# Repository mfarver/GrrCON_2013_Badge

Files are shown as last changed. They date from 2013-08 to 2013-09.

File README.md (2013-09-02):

GrrCON_2013_Badge
=================

Schematics, Board Designs and code for GrrCON 2013 Badges.

Schematic and Board layouts require Eagle 6.4.

Badge is based on Arduino Uno Rev 3.  http://arduino.cc

The board layout and schematic are released under the Creative Commons Share Alike license.  The GrrCON "skull" outline of the board should not be used without permission.

When programming the bootloader on the Main ATMEGA328P processor fuses are:
efuse:0x06 hfuse:0xD6 lfuse:0x7F

Custom bootloader and board definition in the hardware directory.

https://github.com/arduino/Arduino/blob/master/hardware/arduino/firmwares/atmegaxxu2/Arduino-COMBINED-dfu-usbserial-atmega16u2-Uno-Rev3.hex
lfuse:w:0xFF:m hfuse:w:0xD9:m efuse:w:0xF4:m lock:w:0x0F:m

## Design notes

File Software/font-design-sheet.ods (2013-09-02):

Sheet: Sheet1
 |  | 1 |  | 1 |  | 1 |  |  |  |  |  |  |  | 1 |  |  |  |  |  |  |  |  | 1 | 1 |  |  |  |  | 1 |  |  |  | 1 |  | 1
 |  | 1 |  | 1 |  | 1 |  | 1 |  | 1 |  |  | 1 | 1 | 1 | 1 | 1 |  |  |  | 1 | 1 |  |  | 1 |  |  |  | 1 |  |  | 1 |  |  |  | 1
 |  | 1 | 1 |  | 1 |  | 1 | 1 | 1 | 1 | 1 | 1 |  |  |  |  |  |  |  | 1 |  | 1 |  | 1 |  |  |  | 1 |  |  | 1 |  |  |  |  |  | 1
 |  | 1 |  |  |  |  |  | 1 |  | 1 |  |  | 1 | 1 | 1 |  |  |  | 1 |  |  |  | 1 |  |  |  |  |  |  |  | 1 |  |  |  |  |  | 1
 |  | 1 |  |  |  |  | 1 | 1 | 1 | 1 | 1 |  |  |  |  | 1 |  | 1 |  |  |  | 1 |  | 1 |  | 1 |  |  |  |  | 1 |  |  |  |  |  | 1
 |  |  |  |  |  |  |  | 1 |  | 1 |  | 1 | 1 | 1 | 1 |  | 1 |  |  |  | 1 | 1 |  |  | 1 |  |  |  |  |  |  | 1 |  |  |  | 1
 |  | 1 |  |  |  |  |  |  |  |  |  |  |  | 1 |  |  |  |  |  |  |  |  | 1 | 1 |  | 1 |  |  |  |  |  |  | 1 |  | 1
SPC | ! |  | “ |  |  |  | # |  |  |  |  | $ |  |  |  |  | % |  |  |  |  | & |  |  |  |  | ' |  |  | ( |  |  |  | )
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

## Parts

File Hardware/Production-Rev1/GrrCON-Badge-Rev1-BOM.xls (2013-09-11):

PARTS LIST FOR GRRCON 2013 BADGE
Qty | Value | Device | Part Number | Digikey Part | Parts
1 | 200ma | PTC-FUSE-US1206 | 0ZCA0020FF2E | 507-1478-1-ND | F2
1 | 1Mohm | 0805 Resistor 5% | ERJ-6GEYJ105V | P1.0MACT-ND | R1
2 | 270ohm | RESISTOR-DIL_4R-NCAY16 | CAY16-271J4LF | CAY16-271J4LFCT-ND | RN1, RN2
1 | 1kohm | RESISTOR-DIL_4R-NCAY16 | CAY16-102J4GLF | CAY16-102J4GLFCT-ND | RN3
3 | 1uf | 0805 Ceramic Cap | CC0805ZRY5V7BB105 | 311-1457-1-ND | C3, C4, C8
2 | 10k | 0805 Resistor 5% | ERJ-6GEYJ103V | P10KACT-ND | R3, R4
1 | 16mhz | CRYSTALSM49 | ABLS-16.000MHZ-B4-T | 535-10226-1-ND | Q1
2 | 22 ohm | 0805 Resistor 5% | ERJ-6GEYJ220V | P22ACT-ND | R6, R7
2 | 22pf | 0805 Ceramic Cap | CC0805JRNPO9BN220 | 311-1103-1-ND | C9, C11
2 | 74LS595D | 74LS595D shift register | 74HC595D,112 | 568-1483-1-ND | IC3, IC4
5 | 100n | 0805 Ceramic Cap | CC0805ZRY5V9BB104 | 311-1361-1-ND | C1, C2, C5, C6, C7
1 | ATMEGA16U2AU | ATMEGA16U2AU | ATMEGA16U2AU | ATMEGA16U2-AU-ND | IC1
1 | BLM21 | WE-CBF_0805 | BLM21PG221SN1D | 490-1054-1-ND | L1 |  | not populated on production
4 | CD1206-S01575 | DIODE-MINIMELF | CD1206-S01575 | CD1206-S01575CT-ND | D1, D2, D3, D4 |  | depending on LED color D1 may have to be replaced with a zero ohm jumper or Schottky diode
2 | CG0603MLC-05E | VARISTORCN0603 | CG0603MLC-05E | CG0603MLC-05ECT-ND | Z1, Z2 |  | not populated on production
1 | CSTCE16M0V53-R0 16MHZ | RESONATORMU | CSTCE16M0V53-R0 | 490-1198-6-ND | Y2
56 | Varied colors | LEDCHIP-LED0603 |  |  | LED1-LED56
1 | KEYSTONE_COIN2450 | KEYSTONE_COIN2450 | 3009 | 3009K-ND | B1
1 | MCP1703CB | MCP1703CB | MCP1703T-3302E/CB | MCP1703T-3302E/CBCT-ND | IC5
1 | PTS645SMT | PTS645SMT | PTS645SH50SMTR92 LFS | CKN9085CT-ND | SW1
1 | ATMEGA328P-AU | ATMEGA328P-AU | ATMEGA328P-AU | ATMEGA328P-AU-ND | IC2
 | Errata:
 | The pad layout of the pushbutton is wrong and will hold the system in reset. The trace between the lower two pads should be cut, and the upper right leg removed from the switch before soldering
 | The ATMEGA328P processor power net is not connected. A fix wire must be run from the lower (ungrounded) pad of C6 to a nearby VCC pad (we recommended pin 10 of IC4)
 | The forward voltage drop of diode D1 lowers the battery voltage enough that the white LEDs will not light. On most boards D1 is replaced with a 0 ohm jumper.
 | CAUTION: If D1 is replaced with a jumper the battery is not protected from the USB voltage. DO NOT LEAVE BATTERY INSERTED WHEN USB IS CONNECTED!
 | Schematics, code and layouts are available at https://github.com/mfarver/GrrCON_2013_Badge
 |  |  |  | Ebay link for LEDs | Cost each | Reel
 |  |  |  | http://www.ebay.com/itm/4000-pcs-one-reel-SMD-SMT-0603-Super-bright-White-LED-lamp-Bulb-HIGH-QUALITY-/300914219557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 | $62.00 | 2 | $124.00
 |  |  |  | http://www.ebay.com/itm/4000-pcs-one-reel-SMD-SMT-0603-Super-bright-Yellow-LED-lamp-Bulb-GOOD-QUALITY-/121120068712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 | $50.00 | 1 | $50.00
 |  |  |  | http://www.ebay.com/itm/4000-pcs-one-reel-SMD-SMT-0603-Super-bright-BLUE-LED-lamp-Bulb-GOOD-QUALITY-/290925081469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 | 50 | 1 | $50.00

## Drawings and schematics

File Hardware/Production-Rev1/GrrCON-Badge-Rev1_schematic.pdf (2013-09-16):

# GrrCON 2013 Badge

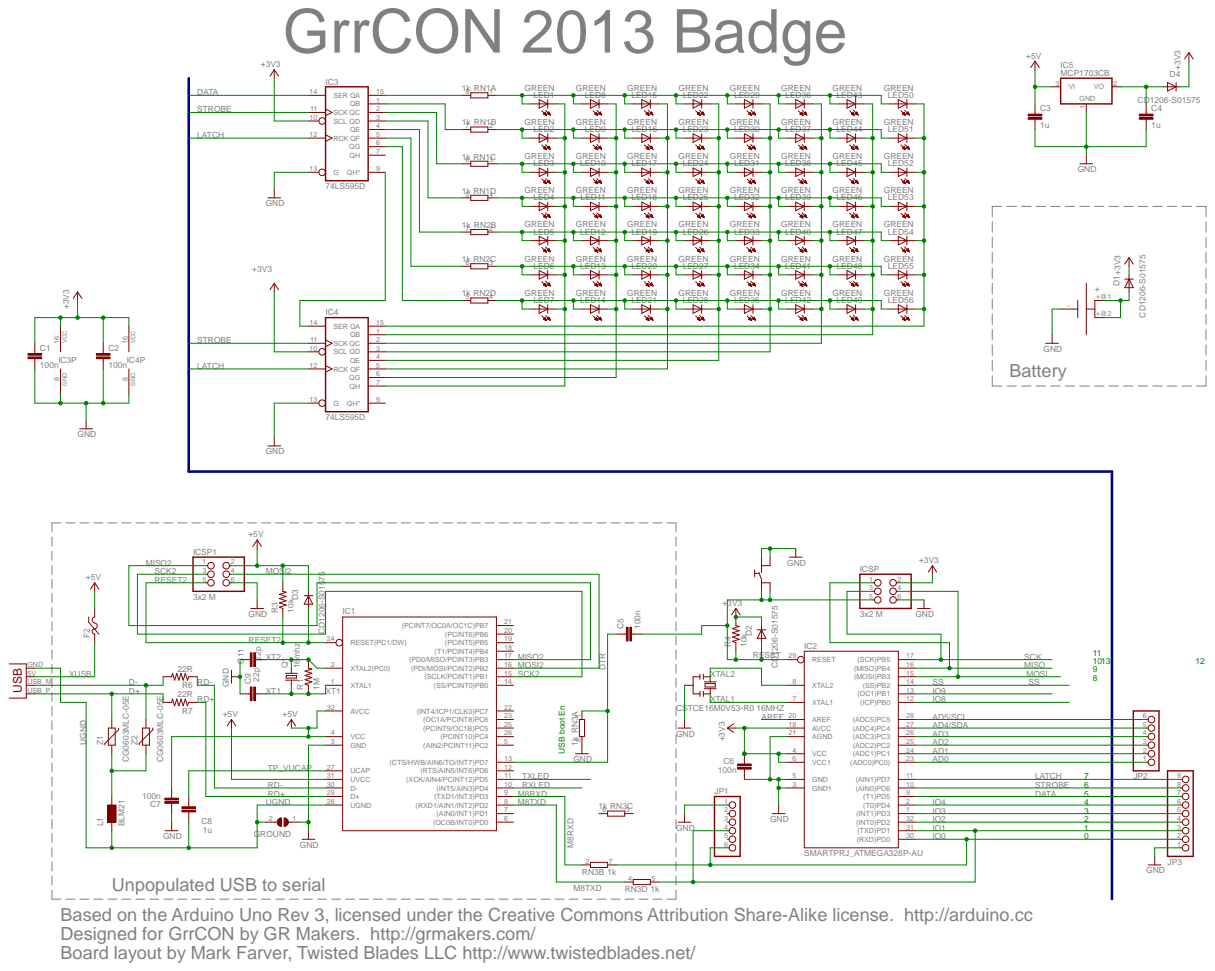
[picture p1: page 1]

Unpopulated USB to serial
Based on the Arduino Uno Rev 3, licensed under the Creative Commons Attribution Share-Alike license. http://arduino.cc
Designed for GrrCON by GR Makers. http://grmakers.com/
Board layout by Mark Farver, Twisted Blades LLC http://www.twistedblades.net/

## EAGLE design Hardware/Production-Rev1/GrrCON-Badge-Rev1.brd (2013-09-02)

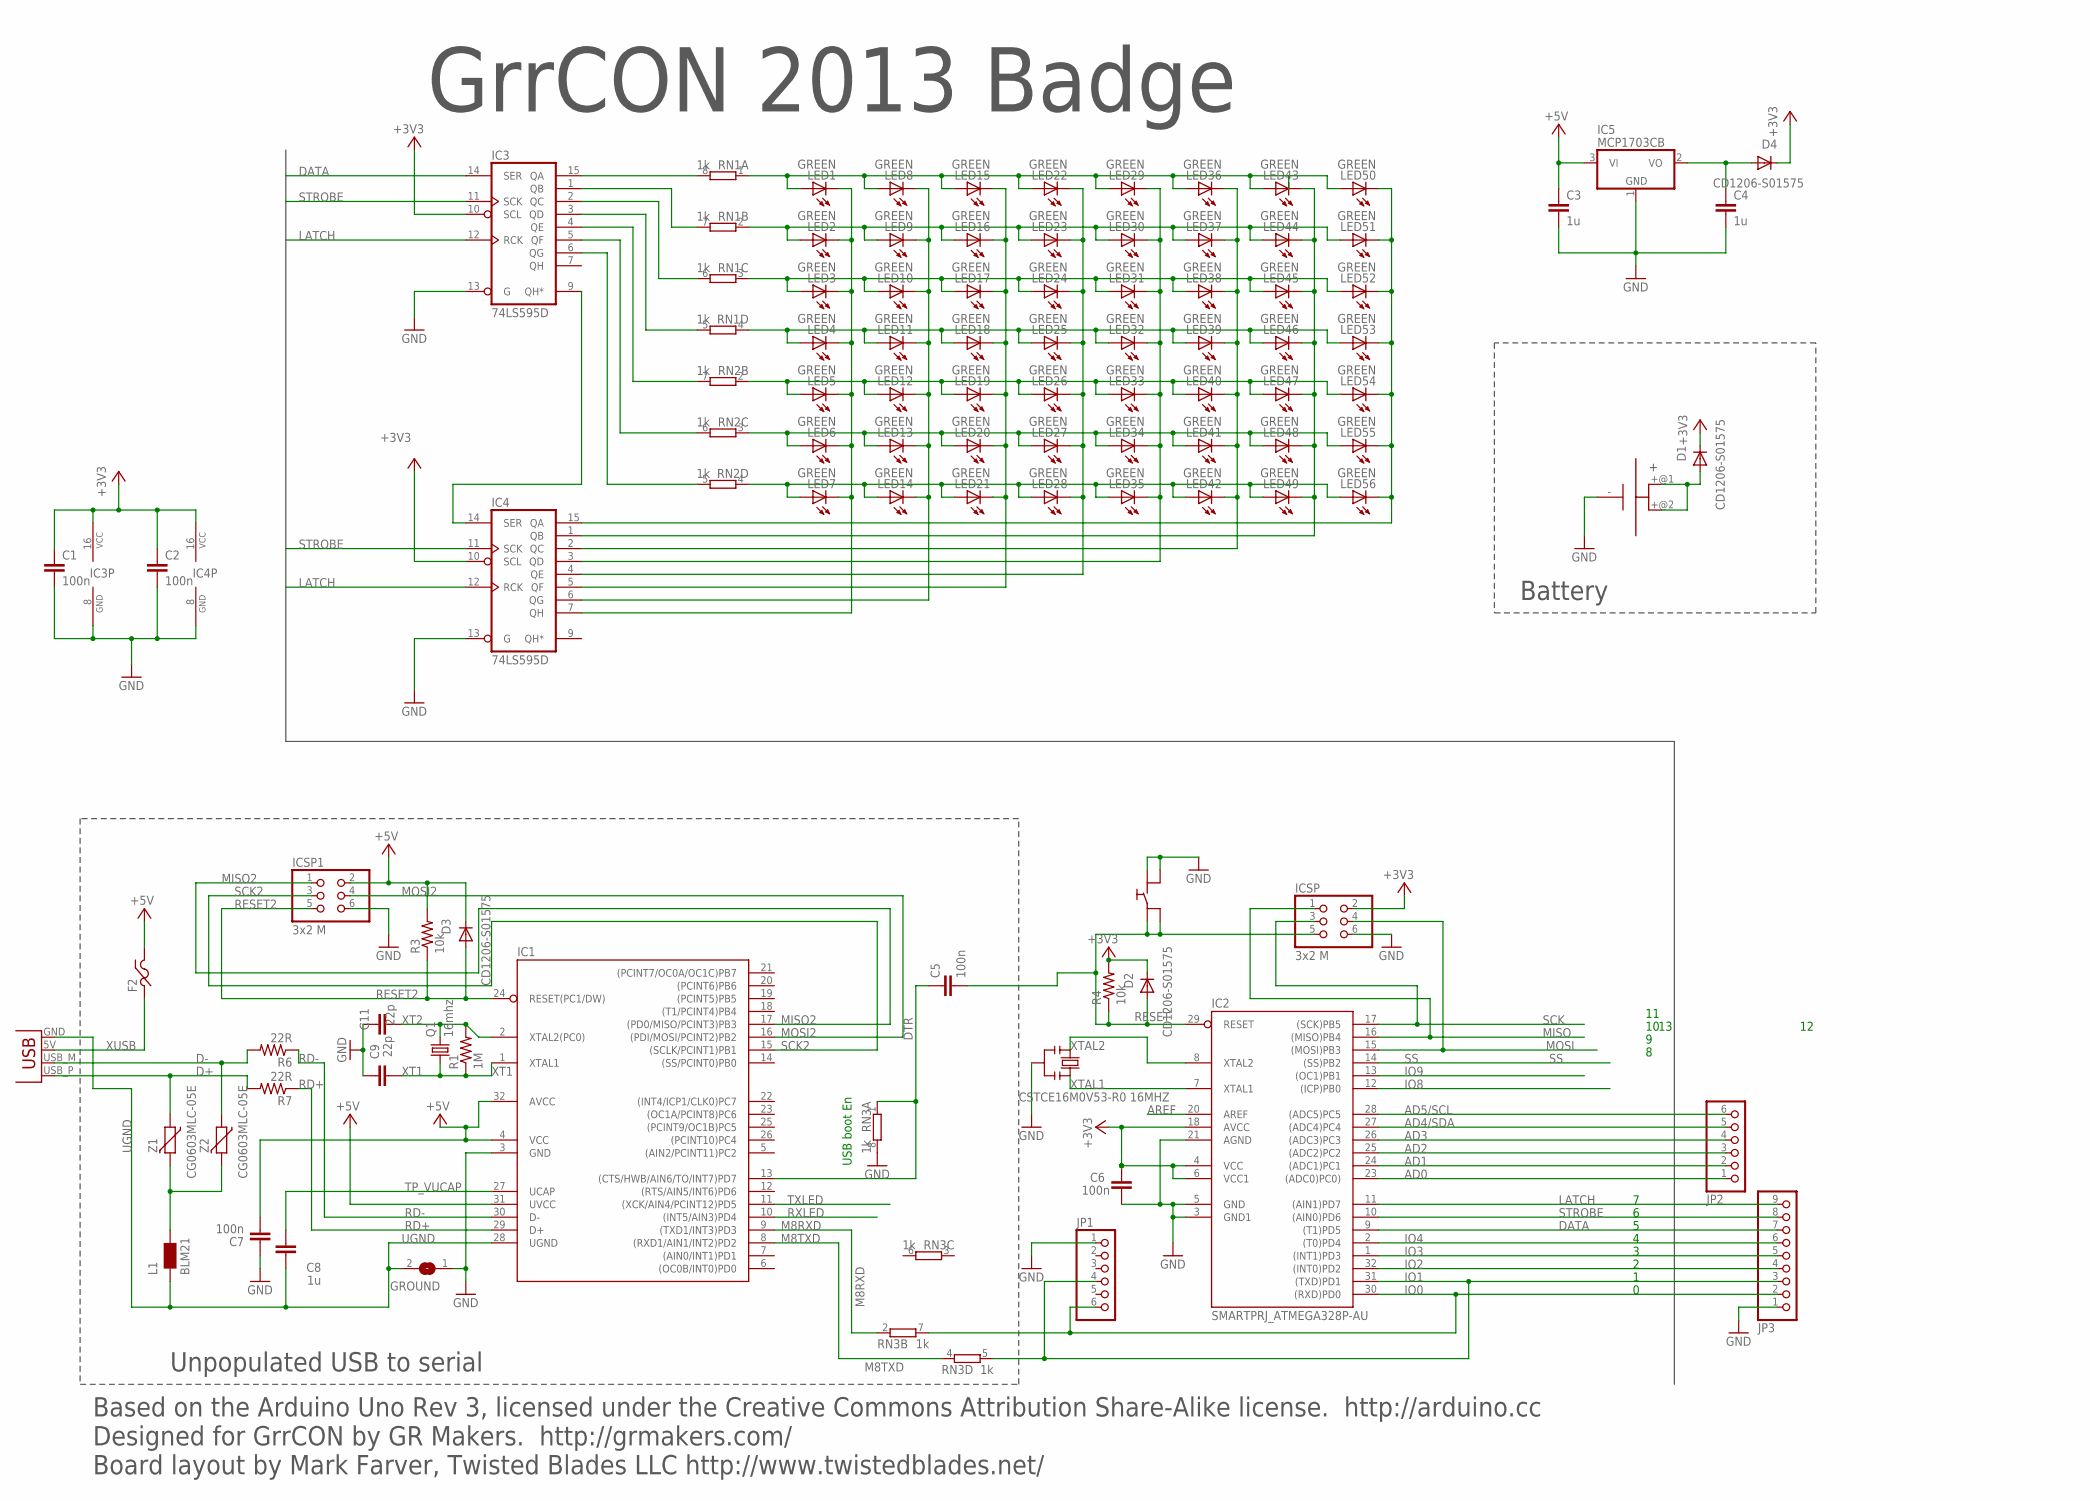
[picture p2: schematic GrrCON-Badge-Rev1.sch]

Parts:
B1: KEYSTONE_COIN2450; 3009
C1, C2, C5, C6, C7: 100n; C0805
C3, C4, C8: 1u; C0805
C9, C11: 22p; C0805
D1, D2, D3, D4: CD1206-S01575; MINIMELF
F2: PTC-FUSE-US1206; F1206
GROUND: SJ
IC1: ATMEGA16U2AU; SMARTPRJ_TQFP32-08
IC2: SMARTPRJ_ATMEGA328P-AU; SMARTPRJ_TQFP32-08
IC3, IC4: 74LS595D; SO16
IC5: MCP1703CB; SOT23
ICSP, ICSP1: 3x2 M; 2X03
JP1, JP2: PINHD-1X6; 1X06
JP3: PINHD-1X9; 1X09
L1: BLM21; 0805
LED1, LED2, LED3, LED4, LED5, LED6, LED7, LED8, LED9, LED10, LED11, LED12, LED13, LED14, LED15, LED16, LED17, LED18, LED19, LED20, LED21, LED22, LED23, LED24, LED25, LED26, LED27, LED28, LED29, LED30, LED31, LED32, LED33, LED34, LED35, LED36, LED37, LED38, LED39, LED40, LED41, LED42, LED43, LED44, LED45, LED46, LED47, LED48, LED49, LED50, LED51, LED52, LED53, LED54, LED55, LED56: GREEN; CHIPLED_0603
Q1: 16mhz; SM49
R1: 1M; R0805
R3, R4: 10k; R0805
R6, R7: 22R; R0805
RN1, RN2, RN3: 1k; RESISTOR-DIL_CAY16
SW1: PTS645SMT
X1: USBPCB; USB-A-PCB
Y2: CSTCE16M0V53-R0 16MHZ; RESONATOR
Z1, Z2: CG0603MLC-05E; CT/CN0603

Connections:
+3V3: C1.1, C2.1, C6.2, D1.C, D2.C, D4.C, IC2.4 (VCC), IC2.6 (VCC1), IC2.18 (AVCC), IC3.10 (SCL), IC3.16 (VCC), IC4.10 (SCL), IC4.16 (VCC), ICSP.2, R4.2
+5V: C3.1, C7.1, D3.C, F2.2, IC1.4 (VCC), IC1.31 (UVCC), IC1.32 (AVCC), IC5.3 (VI), ICSP1.2, R3.2
AD0: IC2.23 ((ADC0)PC0)), JP2.1
AD1: IC2.24 ((ADC1)PC1), JP2.2
AD2: IC2.25 ((ADC2)PC2), JP2.3
AD3: IC2.26 ((ADC3)PC3), JP2.4
AD4/SDA: IC2.27 ((ADC4)PC4), JP2.5
AD5/SCL: IC2.28 ((ADC5)PC5), JP2.6
AREF: IC2.20 (AREF)
D+: R7.2, X1.USB_P (D+), Z1.1
D-: R6.2, X1.USB_M (D-), Z2.1
DATA: IC2.9 ((T1)PD5), IC3.14 (SER), JP3.7
DTR: C5.1, IC1.13 ((CTS/HWB/AIN6/TO/INT7)PD7), RN3.1
GND: B1.-, C1.2, C2.2, C3.2, C4.2, C6.1, C7.2, C9.2, C11.2, GROUND.1, IC1.3 (GND), IC2.3 (GND1), IC2.5 (GND), IC2.21 (AGND), IC3.8 (GND), IC3.13 (G), IC4.8 (GND), IC4.13 (G), IC5.1 (GND), ICSP.6, ICSP1.6, JP1.1, JP3.1, RN3.8 (2), SW1.2A, SW1.2B, Y2.2
IO0: IC2.30 ((RXD)PD0), JP1.6, JP3.2, RN3.7 (2)
IO1: IC2.31 ((TXD)PD1), JP1.4, JP3.3, RN3.5 (2)
IO2: IC2.32 ((INT0)PD2), JP3.4
IO3: IC2.1 ((INT1)PD3), JP3.5
IO4: IC2.2 ((T0)PD4), JP3.6
IO8: IC2.12 ((ICP)PB0)
IO9: IC2.13 ((OC1)PB1)
LATCH: IC2.11 ((AIN1)PD7), IC3.12 (RCK), IC4.12 (RCK), JP3.9
M8RXD: IC1.9 ((TXD1/INT3)PD3), RN3.2 (1)
M8TXD: IC1.8 ((RXD1/AIN1/INT2)PD2), RN3.4 (1)
MISO: IC2.16 ((MISO)PB4), ICSP.1
MISO2: IC1.17 ((PD0/MISO/PCINT3)PB3), ICSP1.1
MOSI: IC2.15 ((MOSI)PB3), ICSP.4
MOSI2: IC1.16 ((PDI/MOSI/PCINT2)PB2), ICSP1.4
unnamed: IC4.7 (QH), LED1.C, LED2.C, LED3.C, LED4.C, LED5.C, LED6.C, LED7.C
unnamed: LED2.A, LED9.A, LED16.A, LED23.A, LED30.A, LED37.A, LED44.A, LED51.A, RN1.2 (1)
unnamed: IC3.6 (QG), RN2.5 (2)
unnamed: LED3.A, LED10.A, LED17.A, LED24.A, LED31.A, LED38.A, LED45.A, LED52.A, RN1.3 (1)
unnamed: LED4.A, LED11.A, LED18.A, LED25.A, LED32.A, LED39.A, LED46.A, LED53.A, RN1.4 (1)
unnamed: IC3.9 (QH*), IC4.14 (SER)
unnamed: IC3.5 (QF), RN2.6 (2)
unnamed: IC3.4 (QE), RN2.7 (2)
unnamed: IC3.3 (QD), RN1.5 (2)
unnamed: IC4.6 (QG), LED8.C, LED9.C, LED10.C, LED11.C, LED12.C, LED13.C, LED14.C
unnamed: IC3.2 (QC), RN1.6 (2)
unnamed: IC3.1 (QB), RN1.7 (2)
unnamed: IC3.15 (QA), RN1.8 (2)
unnamed: B1.+@1 (+), B1.+@2 (+), D1.A
unnamed: C4.1, D4.A, IC5.2 (VO)
unnamed: IC4.5 (QF), LED15.C, LED16.C, LED17.C, LED18.C, LED19.C, LED20.C, LED21.C
unnamed: IC4.4 (QE), LED22.C, LED23.C, LED24.C, LED25.C, LED26.C, LED27.C, LED28.C
unnamed: IC4.3 (QD), LED29.C, LED30.C, LED31.C, LED32.C, LED33.C, LED34.C, LED35.C
unnamed: IC4.2 (QC), LED36.C, LED37.C, LED38.C, LED39.C, LED40.C, LED41.C, LED42.C
unnamed: IC4.1 (QB), LED43.C, LED44.C, LED45.C, LED46.C, LED47.C, LED48.C, LED49.C
unnamed: IC4.15 (QA), LED50.C, LED51.C, LED52.C, LED53.C, LED54.C, LED55.C, LED56.C
unnamed: LED5.A, LED12.A, LED19.A, LED26.A, LED33.A, LED40.A, LED47.A, LED54.A, RN2.2 (1)
unnamed: LED6.A, LED13.A, LED20.A, LED27.A, LED34.A, LED41.A, LED48.A, LED55.A, RN2.3 (1)
unnamed: LED7.A, LED14.A, LED21.A, LED28.A, LED35.A, LED42.A, LED49.A, LED56.A, RN2.4 (1)
unnamed: LED1.A, LED8.A, LED15.A, LED22.A, LED29.A, LED36.A, LED43.A, LED50.A, RN1.1
RD+: IC1.29 (D+), R7.1
RD-: IC1.30 (D-), R6.1
RESET: C5.2, D2.A, IC2.29 (RESET), ICSP.5, R4.1, SW1.1A, SW1.1B
RESET2: D3.A, IC1.24 (RESET(PC1/DW)), ICSP1.5, R3.1
RXLED: IC1.10 ((INT5/AIN3)PD4)
SCK: IC2.17 ((SCK)PB5), ICSP.3
SCK2: IC1.15 ((SCLK/PCINT1)PB1), ICSP1.3
SS: IC2.14 ((SS)PB2)
STROBE: IC2.10 ((AIN0)PD6), IC3.11 (SCK), IC4.11 (SCK), JP3.8
TP_VUCAP: C8.1, IC1.27 (UCAP)
TXLED: IC1.11 ((XCK/AIN4/PCINT12)PD5)
UGND: C8.2, GROUND.2, IC1.28 (UGND), L1.1, X1.GND
USHIELD: L1.2, Z1.2, Z2.2
XT1: C9.1, IC1.1 (XTAL1), Q1.1, R1.1
XT2: C11.1, IC1.2 (XTAL2(PC0)), Q1.2, R1.2
XTAL1: IC2.7 (XTAL1), Y2.3
XTAL2: IC2.8 (XTAL2), Y2.1
XUSB: F2.1, X1.5V (VBUS)

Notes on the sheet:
USB boot En
Unpopulated USB to serial
Battery
GrrCON 2013 Badge
Based on the Arduino Uno Rev 3, licensed under the Creative Commons Attribution Share-Alike license. http://arduino.cc Designed for GrrCON by GR Makers. http://grmakers.com/ Board layout by Mark Farver, Twisted Blades LLC http://www.twistedblades.net/

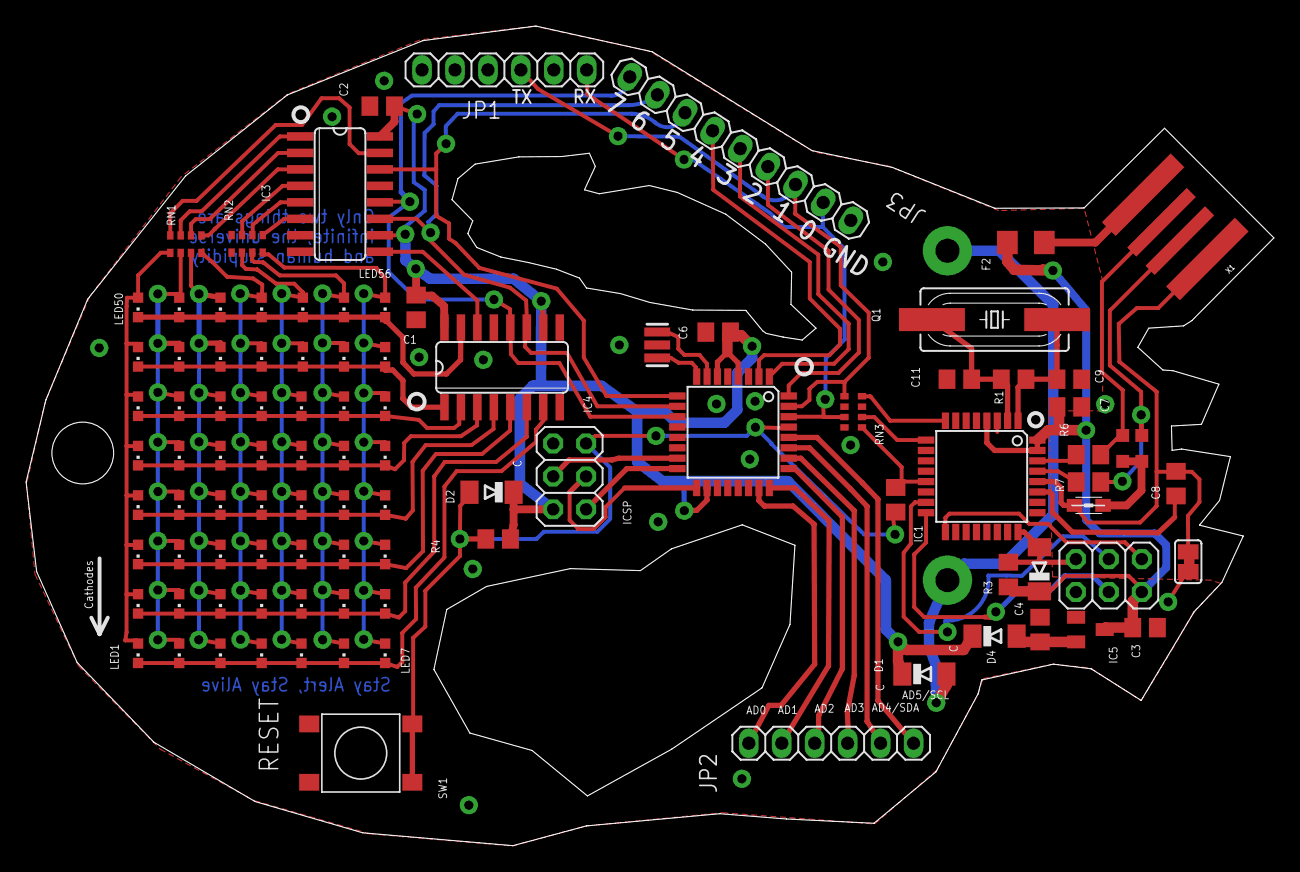
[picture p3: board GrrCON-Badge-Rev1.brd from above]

Board: 2 copper layers, 96.2 x 63.2 mm, 98 parts (1 on the bottom side), 65 nets.

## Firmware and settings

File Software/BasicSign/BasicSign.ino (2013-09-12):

/* Example scrolling signboard app for GrrCON 2013 badges */
/* Author: Mark Farver                                    */
/* Date:   26 Aug 2013                                    */
/*
The MIT License (MIT)

Copyright (c) 2013 Mark Farver

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
THE SOFTWARE IS PROVIDED "AS IS", WITHOUT WARRANTY OF ANY KIND, EXPRESS OR
IMPLIED, INCLUDING BUT NOT LIMITED TO THE WARRANTIES OF MERCHANTABILITY,
FITNESS FOR A PARTICULAR PURPOSE AND NONINFRINGEMENT. IN NO EVENT SHALL THE
AUTHORS OR COPYRIGHT HOLDERS BE LIABLE FOR ANY CLAIM, DAMAGES OR OTHER
LIABILITY, WHETHER IN AN ACTION OF CONTRACT, TORT OR OTHERWISE, ARISING FROM,
OUT OF OR IN CONNECTION WITH THE SOFTWARE OR THE USE OR OTHER DEALINGS IN
THE SOFTWARE.
*/

#include "EEPROM.h"
#include <avr/pgmspace.h>
#include "font5x7.h"

#define shift_latch_bit_pos    7
#define shift_clock_bit_pos    6
#define shift_data_bit_pos     5

#define shift_latch_mask       1 << shift_latch_bit_pos
#define shift_clock_mask       1 << shift_clock_bit_pos
#define shift_data_mask        1 << shift_data_bit_pos

#define MSG_LENGTH_ADDR 0
#define START_OF_MSG_CRC MSG_LENGTH_ADDR + 1
#define START_OF_MSG_ADDR START_OF_MSG_CRC + 4
#define MAX_MSG_LENGTH 255

// last byte of eeprom contains the badge type
#define BADGE_TYPE_ADDR 1023

#define USE_SERIAL

#ifdef USE_SERIAL
unsigned char serial_state;
unsigned long serial_crc;
unsigned long serial_crc2;
unsigned char serial_len;
unsigned char serial_pos;
char serial_message[MAX_MSG_LENGTH+1];
#endif

// how many demo modes do we have?
#define DEMO_COUNT 3

//How many times should we paint the matrix before scrolling it
#define SCROLL_REFRESH 20


boolean reload;
int message_num_cols;
char message[MAX_MSG_LENGTH];

// keeps track of which demo function is being run currently
unsigned char current_demo;
unsigned char demo_speed;

//number columns offset into the message, where screen draw should start
unsigned int current_col;

//keeps track of number of refreshes, counts up to SCROLL_REFRESH
int scroll_count;

unsigned char badge_type;

#define BADGE_TYPE_COUNT 4

const char *default_msg[BADGE_TYPE_COUNT] = {
  "  Speaker",
  "  Staff",
  "  GrrCON",
  "  VIP"
};

const PROGMEM prog_uint32_t crc_table[16] = {
    0x00000000, 0x1db71064, 0x3b6e20c8, 0x26d930ac,
    0x76dc4190, 0x6b6b51f4, 0x4db26158, 0x5005713c,
    0xedb88320, 0xf00f9344, 0xd6d6a3e8, 0xcb61b38c,
    0x9b64c2b0, 0x86d3d2d4, 0xa00ae278, 0xbdbdf21c
};

unsigned long crc_update(unsigned long crc, byte data)
{
    byte tbl_idx;
    tbl_idx = crc ^ (data >> (0 * 4));
    crc = pgm_read_dword_near(crc_table + (tbl_idx & 0x0f)) ^ (crc >> 4);
    tbl_idx = crc ^ (data >> (1 * 4));
    crc = pgm_read_dword_near(crc_table + (tbl_idx & 0x0f)) ^ (crc >> 4);
    return crc;
}

unsigned long crc_string(char *s, unsigned int len)
{
  unsigned long crc = ~0L;
  for(unsigned int i = 0; i < len; ++i)
    crc = crc_update(crc, s[i]);
  crc = ~crc;
  return crc;
}

void store_crc(unsigned int addr, unsigned long crc) {
  for(char i = 0; i < 4; ++i) {
    EEPROM.write(addr + i, ((crc >> (8 * (3-i))) & 0xff));
  }
}

unsigned long load_crc(unsigned int addr) {
  unsigned long crc = 0;
  for(char i = 0; i < 4; ++i) {
    crc |= ((unsigned long) EEPROM.read(addr + i)) << (8 * (3-i));
  }
  return crc;
}

void load_msg() {
  //We need to load the message length
  //The message is stored in a Pascal string in EEPROM
  message_num_cols = EEPROM.read(MSG_LENGTH_ADDR);
  
  // if the EEPROM has not been initialized, we have no message
  if(message_num_cols == 0xFF) {
    message_num_cols = 0;
  }
  
  badge_type = EEPROM.read(BADGE_TYPE_ADDR);
  
  if((message_num_cols == 0) && (badge_type >= BADGE_TYPE_COUNT)) {
    current_demo = 0;
  }
  
  // copy the message from EEPROM (which is slow)
  if(message_num_cols > 0) {
    for(unsigned int i = 0; i < message_num_cols; ++i) {
      message[i] = EEPROM.read(START_OF_MSG_ADDR + i);
    }
    unsigned long msg_crc = crc_string(message, message_num_cols);
    unsigned long stored_crc = load_crc(START_OF_MSG_CRC);

    // if the crc does not match, reject and fall back on defaults
    if(msg_crc != stored_crc) {
      message_num_cols = 0;
    }
  }
  
  // don't combine. if the message failed CRC, we reject it and go to default
  if((message_num_cols == 0) && (badge_type < BADGE_TYPE_COUNT)) {
    while(default_msg[badge_type][message_num_cols]) {
      message[message_num_cols] = default_msg[badge_type][message_num_cols];
      ++message_num_cols;
    }
  }

  message_num_cols *= CHAR_WIDTH;
  current_col = 0;
  scroll_count = 0;
  reload = false;
}

void setup() {                
  pinMode(shift_latch_bit_pos, OUTPUT);     
  pinMode(shift_clock_bit_pos, OUTPUT);     
  pinMode(shift_data_bit_pos, OUTPUT);
  
#ifdef USE_SERIAL
  Serial.begin(9600);
  
  serial_state = 0;
#endif

  current_demo = 0;  
  load_msg();
}

// forward-declare demo routine
void demo();

// the loop routine runs over and over again forever:
void loop() {
  // reload message, if signalled to do so
  if(reload) {
    load_msg();
  }
  
  // startup - show demo
  if(current_demo < DEMO_COUNT) {
    demo();
    return;
  }

  for (int i=0; i < 8; ++i) {
    unsigned int print_col = (current_col + i) % message_num_cols;
    char letter = message[print_col / CHAR_WIDTH];
    if((letter < FIRST_CHAR) || (letter > LAST_CHAR)) {
      letter = FIRST_CHAR;
    }
    unsigned int offset = print_col % CHAR_WIDTH;
    writeCol(i, font5x7[ (letter - FIRST_CHAR) * CHAR_WIDTH + offset]);
  }  

  if ( ++scroll_count > SCROLL_REFRESH ) {
     scroll_count = 0;
     current_col = (current_col + 1) % message_num_cols;
  }
}

#ifdef USE_SERIAL
// Not compatible with Esplora, Leonardo, or Micro
void serialEvent() 
{
  // extremely paranoid protocol:
  // first, look for three 0x03 (ctrl-c)
  // then get the length and crc.
  // then the crc with each byte xored by the length
  // then length bytes of message data.
  
  // to change badge type:
  // three 0x01 followed by the badge type number three times
  
  if (Serial.available() > 0) 
  {
    unsigned char newchar = Serial.read();
    Serial.write(newchar);

    if(0 == serial_state) {
      if(0x03 == newchar) {
        serial_len = 1;
        ++serial_state;
      } else if(0x01 == newchar) {
        serial_state = 100;
        serial_len = 1;
      }
    } else if(1 == serial_state) {
      if(0x03 == newchar) {
        if(++serial_len == 3) {
          ++serial_state;
        }
      } else {
        serial_state = 0;
      }
    } else if(2 == serial_state) {
      serial_len = newchar;
      ++serial_state;
    } else if(3 == serial_state) {
      serial_crc = ((unsigned long)newchar) << 24;
      ++serial_state;
    } else if(4 == serial_state) {
      serial_crc |= ((unsigned long)newchar) << 16;
      ++serial_state;
    } else if(5 == serial_state) {
      serial_crc |= ((unsigned long)newchar) << 8;
      ++serial_state;
    } else if(6 == serial_state) {
      serial_crc |= ((unsigned long)newchar);
      ++serial_state;
    } else if(7 == serial_state) {
      serial_crc2 = ((unsigned long)(newchar ^ serial_len)) << 24;
      ++serial_state;
    } else if(8 == serial_state) {
      serial_crc2 |= ((unsigned long)(newchar ^ serial_len)) << 16;
      ++serial_state;
    } else if(9 == serial_state) {
      serial_crc2 |= ((unsigned long)(newchar ^ serial_len)) << 8;
      ++serial_state;
    } else if(10 == serial_state) {
      serial_crc2 |= ((unsigned long)(newchar ^ serial_len));
      if(serial_crc == serial_crc2) {
        ++serial_state;
        serial_pos = 0;
      } else {
        serial_state = 0;
      }
    } else if(11 == serial_state) {
      serial_message[serial_pos++] = newchar;
      if((serial_pos == serial_len) || (0 == serial_len)) {
        serial_state = 0;
        unsigned long calccrc = crc_string(serial_message, serial_len);
        if(calccrc == serial_crc) {
          for(unsigned char i = 0; i < serial_len; ++i) {
            EEPROM.write(START_OF_MSG_ADDR + i, serial_message[i]);
          }
          EEPROM.write(MSG_LENGTH_ADDR, serial_len);
          store_crc(START_OF_MSG_CRC, serial_crc);
          Serial.print("Wrote message:");
          serial_message[serial_len] = 0;
          Serial.println(serial_message);
          reload = true;
        }
      }
    } else if(100 == serial_state) {
      if(0x01 == newchar) {
        if(++serial_len == 3) {
          ++serial_state;
        }
      } else {
        serial_state = 0;
      }
    } else if(101 == serial_state) {
      newchar -= '0';
      if(newchar < BADGE_TYPE_COUNT) {
        serial_message[0] = newchar;
        serial_len = 1;
        ++serial_state;
      } else {
        serial_state = 0;
      }
    } else if(102 == serial_state) {
      newchar -= '0';
      if(serial_message[0] == newchar) {
        if(++serial_len == 3) {
          Serial.print("Setting badge type to:");
          Serial.println(default_msg[newchar]);
          EEPROM.write(BADGE_TYPE_ADDR, newchar);
          serial_state = 0;
          reload = true;
        }
      } else {
        serial_state = 0;
      }
    }
  }
}
#endif

void writeCol(unsigned int col, unsigned int data){
  //The selected column must be driven low, and the
  //lowest number column is actually the rightmost
  //to simplify things we reorder it by shifting left
  //so column 0 is on the left.
  write_shift_reg( ~(0x80 >> col) );
  write_shift_reg( data );
  strobe_latch();
}

void strobe_latch() {
  PORTD |= shift_latch_mask;
  PORTD &= ~shift_latch_mask;
}

void write_shift_reg(unsigned int write_me) {
  int i;
  int mask = 0x80;
  for (i=0; i<8; ++i) {
    PORTD &= ~shift_clock_mask;  //Set Clock Low
    if ( write_me & mask ) 
      PORTD |= shift_data_mask;
    else   
      PORTD &= ~shift_data_mask;
    PORTD |= shift_clock_mask;  //Set Clock H
    mask >>= 1;
  }
}

void demo() {
  unsigned char demo_speed = 1;
  
  if(0 == message_num_cols) {
    demo_speed = 10;
  }
  
  if(current_demo == 0) {
    // all LEDs on
	for(char i = 0; i < 8; ++i) {
	  writeCol(i, 0x7F);
	}
	if(++scroll_count > (SCROLL_REFRESH * 5 * demo_speed)) {
	  scroll_count = 0;
	  ++current_demo;
	  current_col = 0;
	}
  } else if(current_demo == 1) {
    // first odd lines, then even lines
    char mask = (0x55 << (current_col % 2)) & 0x7F;
    for(char i = 0; i < 8; ++i) {
      writeCol(i, mask);
    }
    if(++scroll_count > (SCROLL_REFRESH * 2 * demo_speed)) {
      scroll_count = 0;
      ++current_col;
    }
    if(current_col > 9) {
      scroll_count = 0;
      ++current_demo;
      current_col = 0;
    }
  } else if(current_demo == 2) {
    // one row on, starting at the top
    char mask = (0x01 << current_col) & 0x7F;
    for(char i = 0; i < 8; ++i) {
      writeCol(i, mask);
    }
    if(++scroll_count > (SCROLL_REFRESH * 2 * demo_speed)) {
      scroll_count = 0;
      ++current_col;
    }
    if(current_col > 6) {
      scroll_count = 0;
      ++current_demo;
      current_col = 0;
    }
  }

  // and loop around if there is no message
  if((current_demo >= DEMO_COUNT) && (message_num_cols == 0)) {
    current_demo = 0;
  }
}

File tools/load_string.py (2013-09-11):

#!/usr/bin/python

import serial, sys, glob, binascii, time

if len(sys.argv) >= 2:
    ser = serial.Serial(sys.argv[1])
else:
    for port in glob.glob('/dev/ttyACM*'):
        try:
            ser = serial.Serial(port, 9600)
        except Exception:
            pass # Fail
        else:
            break
    else:
        sys.exit("No ports found")



txt = raw_input("> ")

crc32 = binascii.crc32(txt) & 0xffffffff

# wait for the badge to finish resetting
time.sleep(2);

for x in range(0, 10):
    ser.write(' ');

#send 3 Ctrl-C
for x in range(0, 3):
    ser.write('\x03');

#send length byte
txtlen = len(txt) & 0xFF;
ser.write(txtlen);

ser.write(crc32 >> 24 & 0xFF);
ser.write(crc32 >> 16 & 0xFF);
ser.write(crc32 >> 8 & 0xFF);
ser.write(crc32 & 0xFF);


ser.write(crc32 >> 24 & 0xFF ^ txtlen);
ser.write(crc32 >> 16 & 0xFF ^ txtlen);
ser.write(crc32 >> 8 & 0xFF ^ txtlen);
ser.write(crc32 & 0xFF ^ txtlen );

for c in txt:
  ser.write(c);

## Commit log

2013-08-27 Initial load of production and prototype eagle files and code
    [GrrCON-Badge-Rev1-BOM.xls, GrrCON-Badge-Rev1.brd, GrrCON-Badge-Rev1.sch]
2013-08-28 Added license header, and fixed overrun
    Fixed issue where last character would read columns from beyond end of
    message array.. now correctly wraps back to the beginning.
    [BasicSign.ino]
2013-08-31 Added 1/8 clock prescaler
    Slowed clock down to improve low voltage performance on cheap batteries.
2013-09-02 Fixed flicker at 2 mhz clock
    Swapped digitalWrite functions for direct port access. Significant
    speed up eliminated flicker
    [font-design-sheet.ods]
2013-09-02 Added custom 2mhz/19200 bootloader
    Added patch to optiboot source to compile a custom bootloader that runs
    at 2mhz. The fuses are now setup to divide the 16mhz external clock by
    8 and brown out detect at 1.8V. This should run at a more battery
    friendly 2mhz down to 1.8V.
    [BasicSign.ino]
2013-09-02 Fixed missing Power Net, spelling
    Fixed Spelling of Arduino on silk and documentation. Fixed missing
    power net to ATMEGA328P processor
    [GrrCON-Badge-Rev1.brd, GrrCON-Badge-Rev1.sch]
2013-09-02 Save message to EEPROM fixes
    Changed the message storage in EEPROM to a Pascal string with the length
    at the start. This allows persistence thru resets/battery changes.
    [BasicSign.ino]
2013-09-02 fix serial noise corrupting message
    Added a write buffer so serial noise when USB is disconnected does not
    trash message. Also three CRs in a row are required to commit message
    [BasicSign.ino]
2013-09-08 global var cleanup. misc fixes.
    [BasicSign.ino]
2013-09-08 fix demo loop off-by-one
    [BasicSign.ino]
2013-09-08 fix small mistake in demo loop
    [BasicSign.ino]
2013-09-10 re-enable serial code
    You know... it helps to use the correct board profile when compiling
    the serial code.
    [BasicSign.ino]
2013-09-10 replace pixel demo with single-row demo
    [BasicSign.ino]
2013-09-10 update serial programming protocol
    update serial programming protocol to be more resistant to noise from
    handling.
    To update, send 9 garbage characters to make certain you are in the base
    mode. space or newline work well for this.
    Then:
    To update the message:
    1. Send three 0x03 characters
    2. Send the message length
    3. Send the CRC32 of the message (big-endian)
    4. Send the CRC xor message length (on each byte)
    5. Send the message
    To change badge type default message:
    1. send three 0x01 characters
    2. send the badge type number three times (in ascii)
    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
    [BasicSign.ino]
2013-09-10 fix code to match last commit comment
    in the previous commit, I said the badge type was sent in ascii and
    that the badge type change attention sequence was 0x01. I forgot to
    make the changes to the code to match.
    [BasicSign.ino]
2013-09-10 missed in previous commit of this file
    [BasicSign.ino]
2013-09-11 Updated BOM
    Updated BOM spreadsheet and added additional comments.
    [GrrCON-Badge-Rev1-BOM.xls]
2013-09-12 Combined load_string and setbadge w/ OS checks
    This file now checks for Linux or OSX, then asks which action you'd
    like to take. Each action has sub-options in order to work with the
    board.
2013-09-16 add PDF of schematic

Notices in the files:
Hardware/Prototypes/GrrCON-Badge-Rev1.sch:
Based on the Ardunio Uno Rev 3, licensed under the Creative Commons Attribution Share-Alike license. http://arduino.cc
